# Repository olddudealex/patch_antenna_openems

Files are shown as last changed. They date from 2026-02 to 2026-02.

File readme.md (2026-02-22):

# openEMS Microstrip Patch Antenna Array Simulation Framework

## Overview

This is an openEMS-based simulation and analysis framework for designing microstrip patch antenna arrays. It automates electromagnetic FDTD (Finite-Difference Time-Domain) simulations for linear arrays of rectangular patch antennas on dielectric substrates, with a focus on ~5.8 GHz applications for millimeter-wave radar systems.

### Key Capabilities
- Build patch antenna arrays procedurally or from STL 3D models
- Run FDTD electromagnetic simulations
- Extract S-parameters (reflection/transmission coefficients)
- Generate comprehensive analysis plots (impedance, radiation patterns, fields)
- Support parametric sweeps for antenna optimization
- Convert time-domain field data to frequency-domain representations
- Export results as multi-page PDF reports

---

## Project Structure

### Primary Analysis Scripts (Entry Points)

**[patch_line_analysis.py](patch_line_analysis.py)** - Procedural patch line array simulation
- Builds geometry directly in CSXCAD without STL
- Simulates a linear array of microstrip patches
- Default configuration: 5 elements, 14.1×19mm patches, 5.8 GHz
- Generates multi-page PDF with S11, Smith chart, field slices, surface currents, and directivity patterns

**[patch_line_analysis_with_feed.py](patch_line_analysis_with_feed.py)** - STL-based array with explicit feed port
- Loads CAD models (STL) and converts them to CSXCAD materials
- Automatic mesh line extraction from STL edges for accurate discretization
- Lumped port feed specification
- Geometry-driven mesh snapping for improved accuracy

**[patch_analysis.py](patch_analysis.py)** - Single-patch parameter sweeps
- Optimization via parametric length/width/inset sweeps
- Per-sweep PDF with resonance characteristics and impedance trends
- Supports quarter-wave matching transformers

**[patch_2port_analysis.py](patch_2port_analysis.py)** - Two-port network analysis
- Analyzes coupled patch pairs
- Generates S2P files for two-port network analysis

### Supporting Modules

**[utils.py](utils.py)** (1052 lines) - Core post-processing library
- **HDF5 Data I/O**: Parse openEMS time-domain field dumps
- **Frequency-Domain Conversion**: DFT and FFT-based spectrum extraction
- **Field Visualization**: 2D colormaps, line cuts, surface current density
- **Network Analysis**: Smith charts, S-parameter plots with bandwidth annotations
- **Parameter Conversions**: S↔ABCD↔Z0 transformations
- **File Export**: Touchstone file generation (.s1p, .s2p)
- **Radiation Patterns**: Directivity plots (linear/dB, polar/Cartesian)

**[stl_model.py](stl_model.py)** - CAD material builder
- Creates CSXCAD structure from STL files
- Loads materials from `freecad_macro_output/`:
  - `top_gen_model.stl` → PEC material (patches)
  - `bottom_gen_model.stl` → Ground plane
  - `substrate_gen_model.stl` → Dielectric
- Assigns material priorities for overlap handling

**[extract_edges_from_stl.py](extract_edges_from_stl.py)** - Mesh extraction tool
- Extracts axis-aligned edges from STL models
- Generates CSV files with mesh coordinates (x, y, z)
- Configurable angle and position tolerances
- Usage: `extract_edges_from_stl.main(["path/to/model.stl"])`

**[apply_meshlines_from_csv.py](apply_meshlines_from_csv.py)** - Grid configuration
- Applies extracted meshlines to CSXCAD grid
- Snaps FDTD grid points to STL geometry edges
- Supports coordinate scaling for unit conversion

---

## Technology Stack

| Component | Purpose |
|---|---|
| **openEMS** | FDTD electromagnetic solver (core physics engine) |
| **CSXCAD** | 3D geometry CAD engine |
| **NumPy** | Numerical array operations and Fourier transforms |
| **Matplotlib** | 2D plotting and multi-page PDF export |
| **h5py** | HDF5 file I/O for field data |
| **scikit-rf** | Network parameter analysis and Smith charts |
| **trimesh** | 3D mesh processing for STL import |

---

## Prerequisites

### System Requirements
- **Python 3.8+** (3.10+ recommended)
- **OpenEMS & CSXCAD** installed with Python bindings
- Windows/Linux/macOS with proper PATH/PYTHONPATH setup

### Installation

```bash
# Install Python dependencies
pip install numpy matplotlib h5py scikit-rf trimesh

# Install openEMS and CSXCAD per official documentation
# Ensure Python modules are importable (update PYTHONPATH if needed)
# On Windows, add DLL directories to PATH
```

---

## Usage

### Quick Start

```bash
# Run procedural patch-line analysis
python patch_line_analysis.py

# Run STL-driven patch-line analysis with feed
python patch_line_analysis_with_feed.py

# Run single patch analysis
python patch_analysis.py
```

### Configuration Parameters

All scripts expose configurable parameters at the top:

```python
# Frequency
f0 = 5.8e9  # Hz - Center frequency
fc = 0.5e9  # Hz - Bandwidth (20 dB corner frequency)

# Substrate (ZYF300CA-P)
substrate_epsR = 3.0
substrate_tan = 0.0018
substrate_thickness = 1.524  # mm

# Patch Geometry
patch_length = 14.1  # mm - Resonant length
patch_width = 19     # mm
patch_number = 5     # Array element count
feed_length = 14.1   # mm
feed_width = 3.9     # mm
feed_R = 50          # Ohm - Feed impedance (50-150Ω typical)

# Output Controls
enable_simulation = 1  # 1: Run FDTD, 0: Post-process only
save_to_pdf = 1       # 1: Batch PDF, 0: Interactive display
draw_CAD = 0          # 1: Preview 3D geometry, 0: Skip
draw_S11 = 1          # Enable/disable specific plots
draw_smith_chart = 1
draw_fields = 1
```

---

## Workflow Pipeline

```
1. Load Configuration
   ↓
2. Build Geometry
   - Procedural: Direct CSXCAD objects
   - STL-based: Load STL → Extract meshlines → Apply grid snapping
   ↓
3. Configure FDTD Solver
   - Set boundary conditions (PML_8)
   - Set excitation (Gaussian pulse)
   - Configure mesh resolution
   ↓
4. Run FDTD Simulation (if enable_simulation=1)
   - Execute openEMS solver
   - Output: HDF5 field dumps (Et.h5, Jt.h5)
   ↓
5. Post-Processing (utils.py)
   - Read HDF5 dumps
   - Convert time-domain → frequency-domain
   - Extract S-parameters
   - Generate visualizations
   ↓
6. Export Results
   - Multi-page PDF report
   - S-parameter files (.s1p, .s2p)
   - Logs and metadata
```

---

## Output Files

### Generated Artifacts

**PDF Reports** - Multi-page analysis with:
- S11 reflection coefficient vs frequency
- Smith chart impedance plots
- E-field snapshots (2D slices)
- Surface current density (magnitude + components)
- Directivity patterns (if NF2FF enabled)

**S-Parameter Files** - Touchstone format (.s1p/.s2p):
- Compatible with RF analysis tools
- Frequency range: typically 4.5–7 GHz
- Example naming: `patch_line_14_1mm_19mm_14_1mm_1mm.s1p`

**Mesh Configuration** - CSV files in `meshlines/`:
- `meshlines_x.csv`, `meshlines_y.csv`, `meshlines_z.csv`
- Coordinate values for FDTD grid optimization

**Temporary Files** - Simulation directory:
- Location: `%TEMP%/patch_line_analysis_TIMESTAMP/`
- Contains: CSX XML, HDF5 field dumps, solver logs

---

## STL-Based Workflow Details

The `patch_line_analysis_with_feed.py` script uses STL geometry:

1. **Expected STL Files** in `./freecad_macro_output/`:
   - `top_gen_model.stl` - PEC patches
   - `bottom_gen_model.stl` - Ground plane
   - `substrate_gen_model.stl` - Dielectric layer
   - Generated by FreeCAD macro exports

2. **Mesh Line Extraction**:
   - Script calls `extract_edges_from_stl.main()` for each STL
   - Generates `meshlines_{x,y,z}.csv` in `meshlines/` directory
   - Axis-aligned edges extracted with configurable tolerances

3. **Grid Application**:
   - `apply_meshlines_from_csv()` reads from `meshlines/` directory
   - Supports coordinate scaling (e.g., mm → m with `scale=1e-3`)
   - Mesh snaps to geometry boundaries for accuracy

4. **Material Assignment**:
   - PEC (priority 10): Conductive patches
   - SUBSTRATE (priority 0): Dielectric layer
   - Ground plane: PEC material

---

## Antenna Design Specifications

### Default Configuration
```
Frequency: 5.8 GHz (C-band radar)
Substrate: ZYF300CA-P
  - Permittivity (εr): 3.0
  - Loss tangent (tan δ): 0.0018
  - Thickness: 1.524 mm
Patch: 14.1 × 19 mm rectangular
Array: 5 elements linear
Feed: 3.9–14.1 mm microstrip line
Impedance: 50–150 Ω (configurable)
Matching: Optional quarter-wave transformers
```

### Simulation Parameters
```
FDTD timesteps: 60,000
End criteria: 1e-5 (-50 dB energy decay)
Boundary conditions: PML_8 (6 faces)
Mesh resolution: λ/20 at f0+fc (~3.4 mm)
Excitation: Gaussian pulse (f0 ± fc)
```

---

## Data Flow Architecture

```
Analysis Script
    ↓
[Build Geometry] ──→ Procedural CSXCAD ──┐
    ↓                                     │
[STL Import] ──→ extract_edges_from_stl ──┤
    ↓            ↓                        │
stl_model.py   meshlines/*.csv           │
(reads from    (writes to meshlines/)    │
freecad_macro_ ↓                         │
output/)   apply_meshlines_from_csv ─────┘
    ↓
[FDTD Solver] ──→ openEMS ──→ HDF5 dumps (temp dir)
    ↓
[Post-Process] ──→ utils.py ──→ read_hdf5_dump()
    ↓                         ↓
    │                    td_to_fd_fft()
    ↓                         ↓
[Visualize] ────────────→ plot_s11(), plot_smith_skrf()
    ↓                    plot_ez_2d(), plot_js_2d()
    │                    plot_directivity_*()
    ↓                         ↓
[Export] ────────────────→ reports/*.pdf + touchstone/*.s1p/.s2p
```

---

## Troubleshooting

### Import Errors

**openEMS or CSXCAD not found**
- Ensure openEMS and CSXCAD are installed with Python bindings
- Verify PATH/PYTHONPATH includes required DLLs and modules (Windows)
- Test: `python -c "import openEMS, CSXCAD"`

**scikit-rf or trimesh not found**
- Install via pip: `pip install scikit-rf trimesh`

### Simulation Issues

**Missing Et.h5/Jt.h5 when enable_simulation=0**
- Re-run with `enable_simulation=1` to regenerate results
- Check temp directory (`%TEMP%/patch_line_analysis_*`) for HDF5 files

**No STL meshlines CSV files appear**
- Ensure `extract_edges_from_stl` runs successfully
- Check that `meshlines/` directory is created (auto-created by script)
- Verify STL file paths in `freecad_macro_output/` are valid
- Check that STL files contain proper meshes

**Simulation fails or crashes**
- Check mesh resolution (too fine → memory issues)
- Verify boundary conditions don't intersect geometry
- Review openEMS error logs in temp directory

---

## Design Patterns

### Configuration-Driven
- All tunable parameters at script top (not in functions)
- Boolean flags for workflow control (`draw_*`, `enable_simulation`)
- Easy parametric sweeps via script modification

### Modular Post-Processing
- Pure functions in `utils.py` (td_to_fd_*, plot_*, conversions)
- Decoupled from FDTD solver → can reuse cached results
- Flexible field slicing with geometry masking

### CAD Integration
- FreeCAD → STL export workflow
- Mesh line extraction for grid optimization
- Material priority system for overlap handling

---

## Project Status

This framework is under active development for antenna design research. The repository contains:
- Multiple parameter sweep campaigns (30+ result PDFs)
- Historical analysis archives in subdirectories
- Evolution from procedural to CAD-based workflows

Recent development focus:
- STL import support for complex geometries
- Mesh optimization and feed modeling
- Documentation and reproducibility improvements

---

## Repository Map

```
├── patch_line_analysis.py              # Main: procedural patch line
├── patch_line_analysis_with_feed.py    # Main: STL-driven analysis
├── patch_analysis.py                   # Main: single patch sweeps
├── patch_2port_analysis.py             # Supplementary: 2-port analysis
├── utils.py                            # Post-processing library
├── stl_model.py                        # STL → CSXCAD conversion
├── extract_edges_from_stl.py           # Mesh line extraction CLI
├── apply_meshlines_from_csv.py         # Grid configuration utility
│
├── freecad_macro_output/               # FreeCAD generated STL models
│   ├── top_gen_model.stl               # PEC patches
│   ├── bottom_gen_model.stl            # Ground plane
│   ├── substrate_gen_model.stl         # Dielectric substrate
│   ├── air_gen_model.stl               # Air volume (optional)
│   └── line_array_openEMS.py           # Auto-generated FreeCAD script
│
├── meshlines/                          # FDTD mesh coordinates
│   ├── meshlines_x.csv
│   ├── meshlines_y.csv
│   └── meshlines_z.csv
│
├── touchstone/                         # S-parameter exports
│   ├── *.s1p                           # Single-port measurements
│   └── *.s2p                           # Two-port measurements
│
└── reports/                            # Analysis PDF reports
    ├── best/                           # Best performing designs
    ├── Hor_Polarity_with_Individual_Feed_Lines/
    ├── Ver_Polarity_with_Individual_Feed_Lines/
    └── Ver_Polarity_with_One_Through_Feed_Line/
```

---

## Summary

This framework integrates openEMS FDTD simulation with comprehensive post-processing for microstrip patch antenna array design. It supports both procedural and CAD-based workflows, with automated S-parameter extraction, field visualization, and professional PDF reporting for parametric design studies and rapid prototyping.

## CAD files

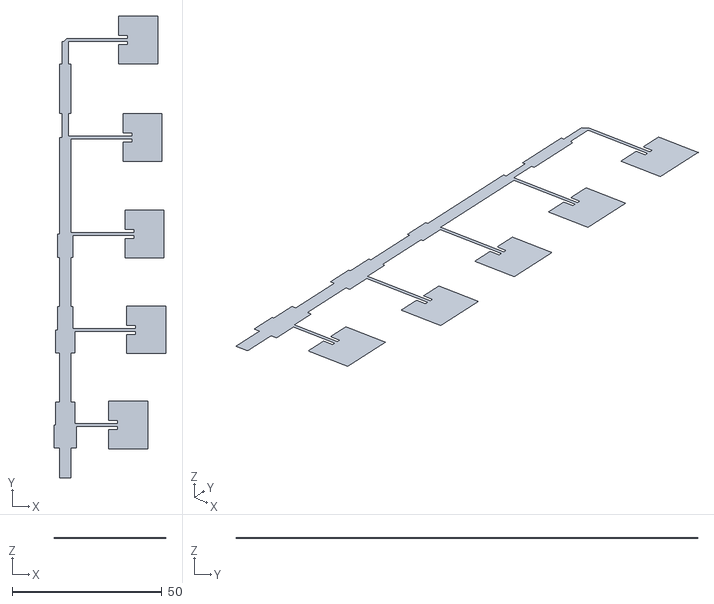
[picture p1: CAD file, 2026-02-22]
freecad_macro_output/top_gen_model.stl
37.3 x 154.3 x 0.035

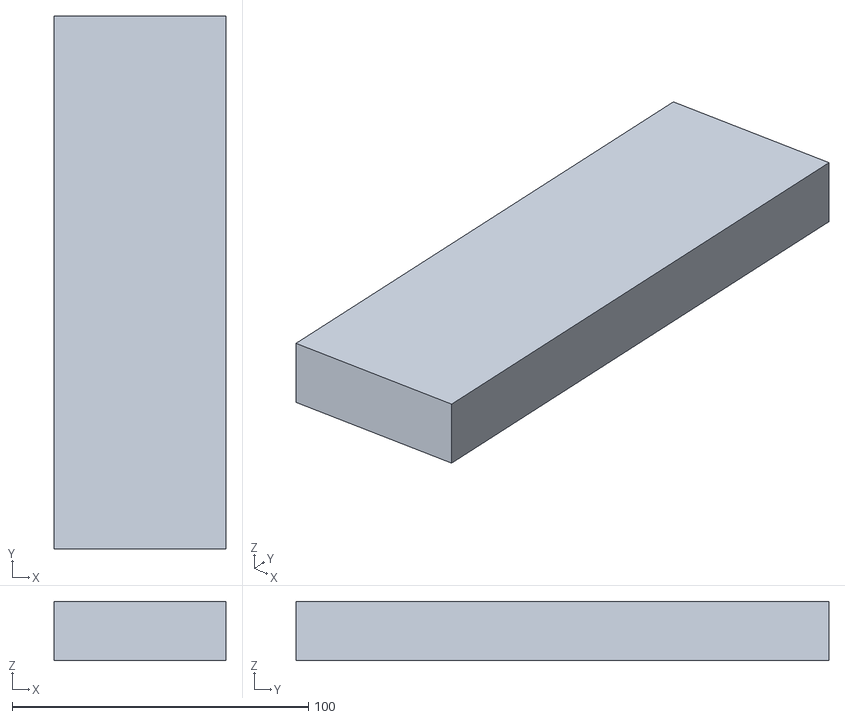
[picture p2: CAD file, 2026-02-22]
freecad_macro_output/air_gen_model.stl
58.0 x 180.0 x 20.0

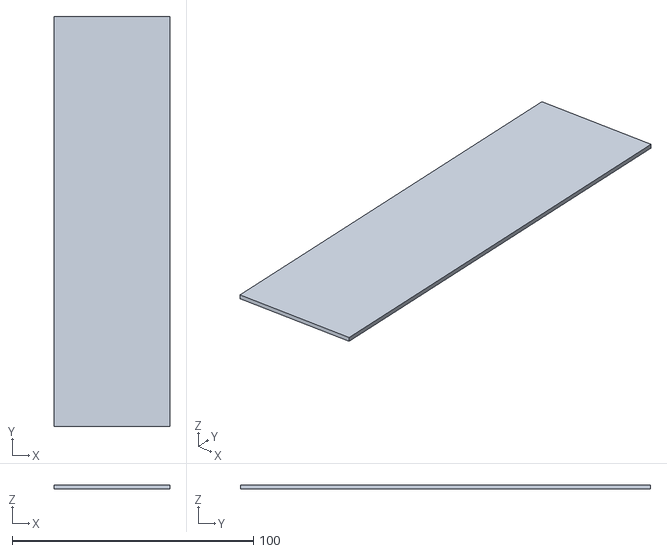
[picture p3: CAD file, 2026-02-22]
freecad_macro_output/substrate_gen_model.stl
48.0 x 170.0 x 1.52

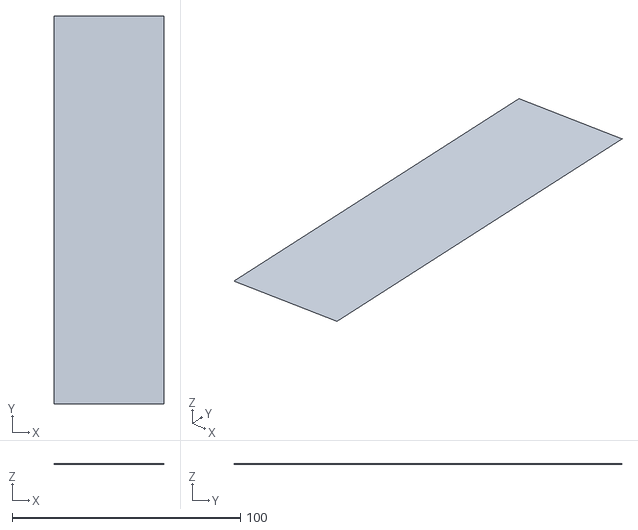
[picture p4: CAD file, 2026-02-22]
freecad_macro_output/bottom_gen_model.stl
48.0 x 170.0 x 0.035

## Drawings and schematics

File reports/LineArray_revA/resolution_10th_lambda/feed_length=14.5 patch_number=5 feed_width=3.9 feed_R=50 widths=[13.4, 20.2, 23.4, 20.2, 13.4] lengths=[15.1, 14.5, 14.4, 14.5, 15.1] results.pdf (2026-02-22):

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

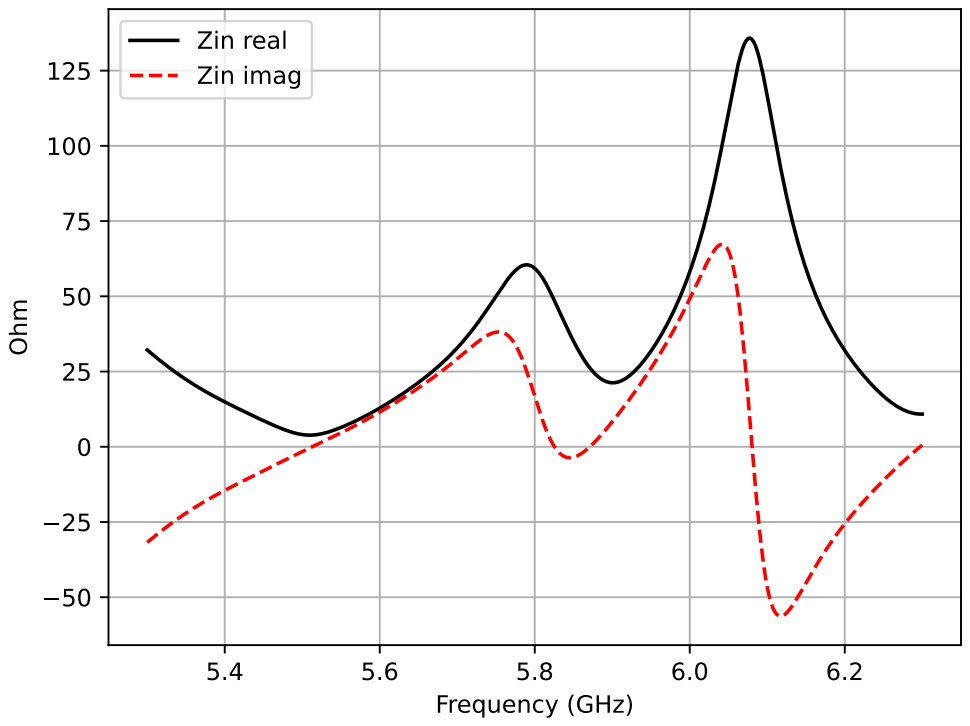
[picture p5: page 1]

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

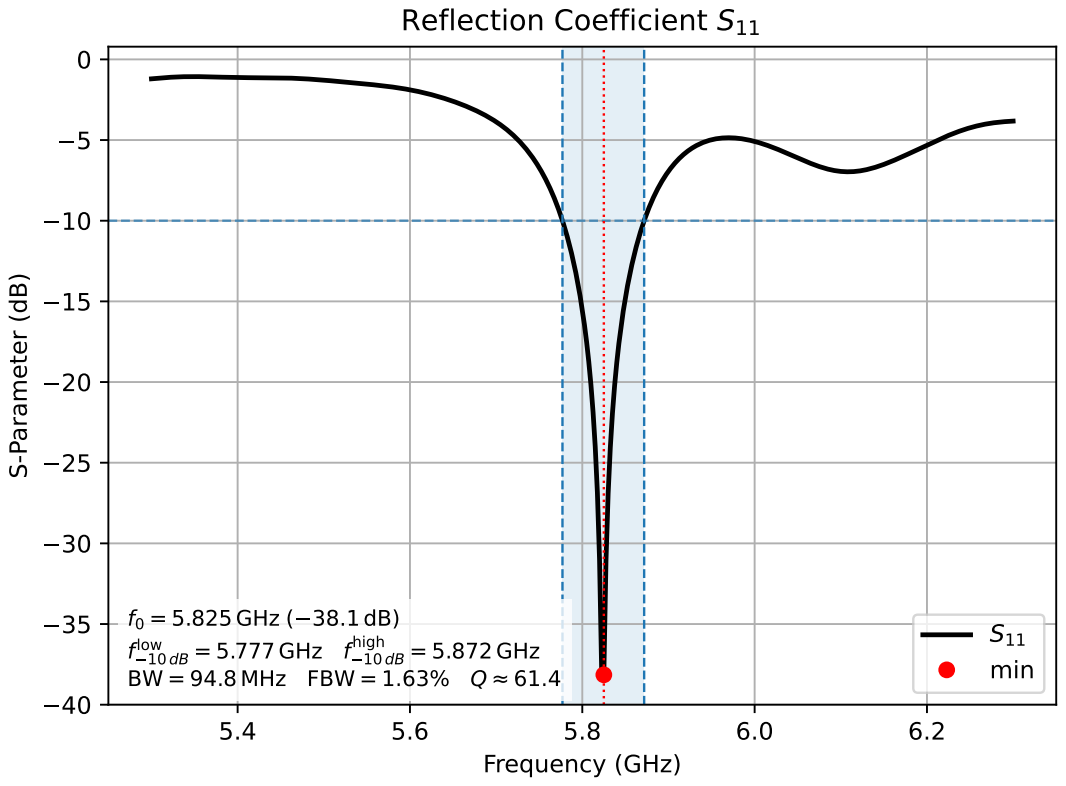
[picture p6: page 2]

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

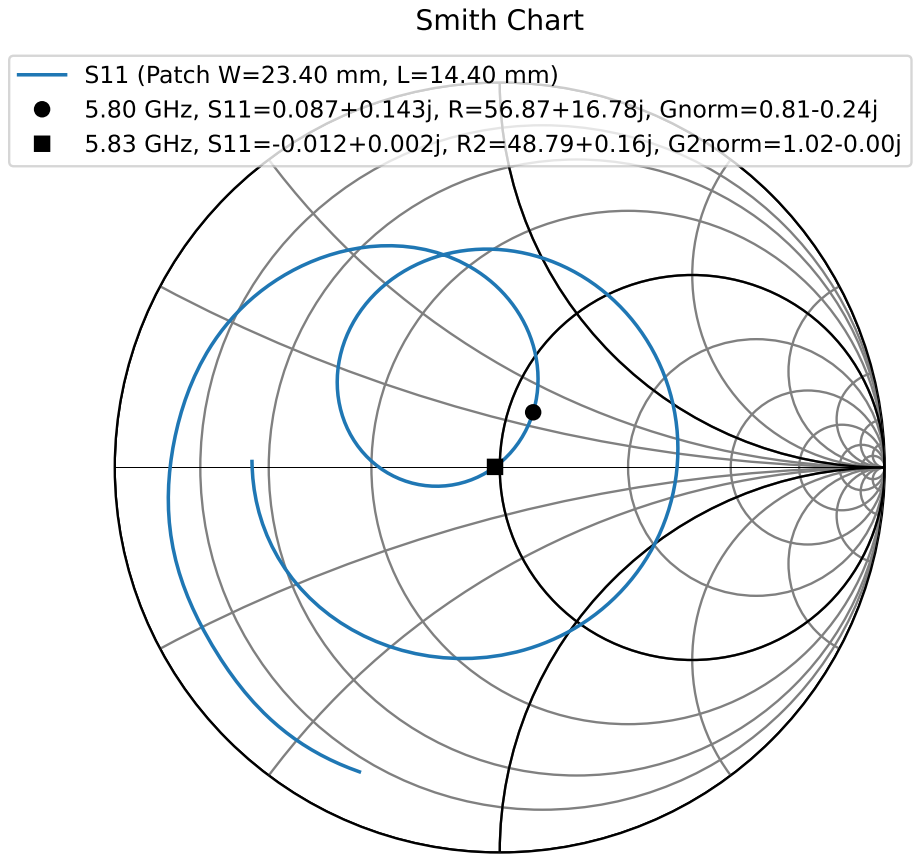
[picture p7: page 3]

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

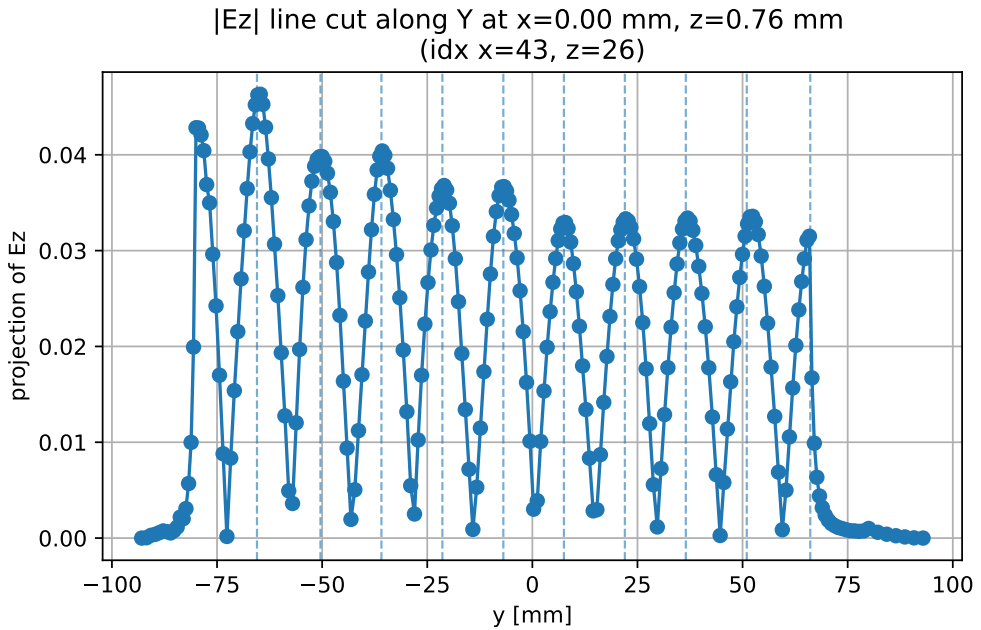
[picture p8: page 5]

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

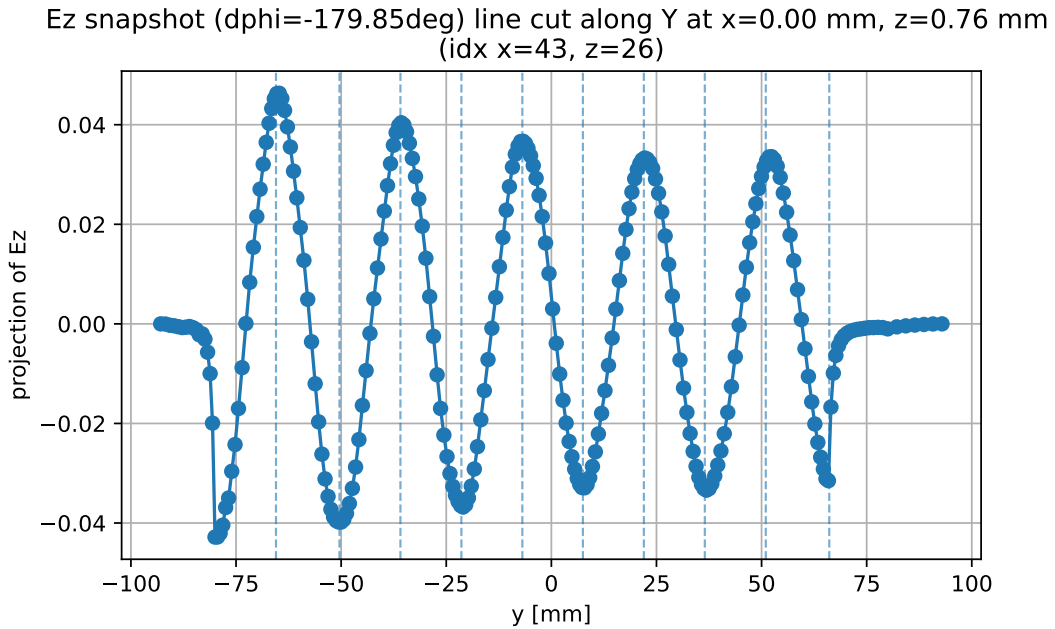
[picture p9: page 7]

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

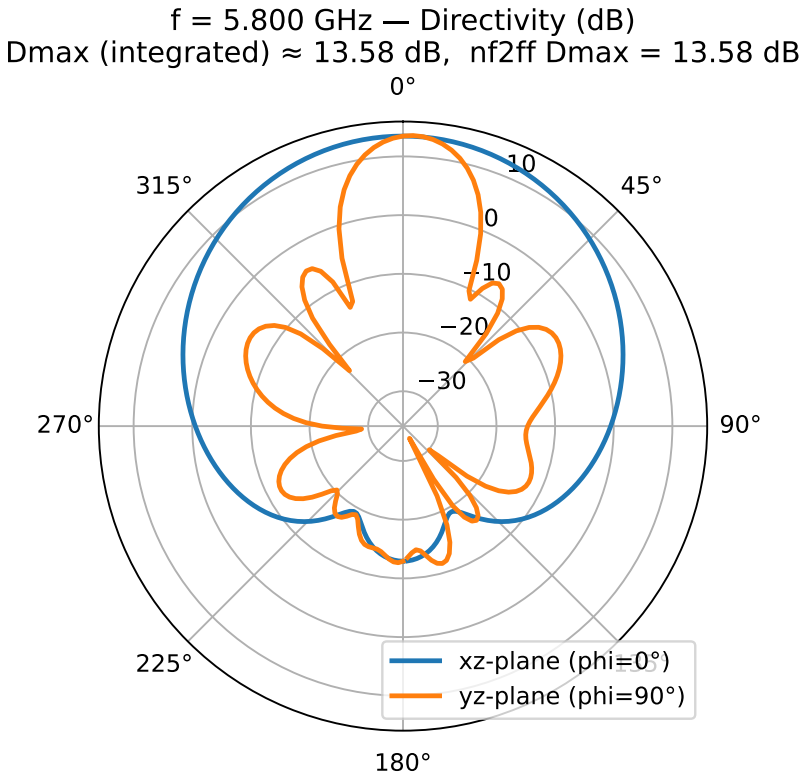
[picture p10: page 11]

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

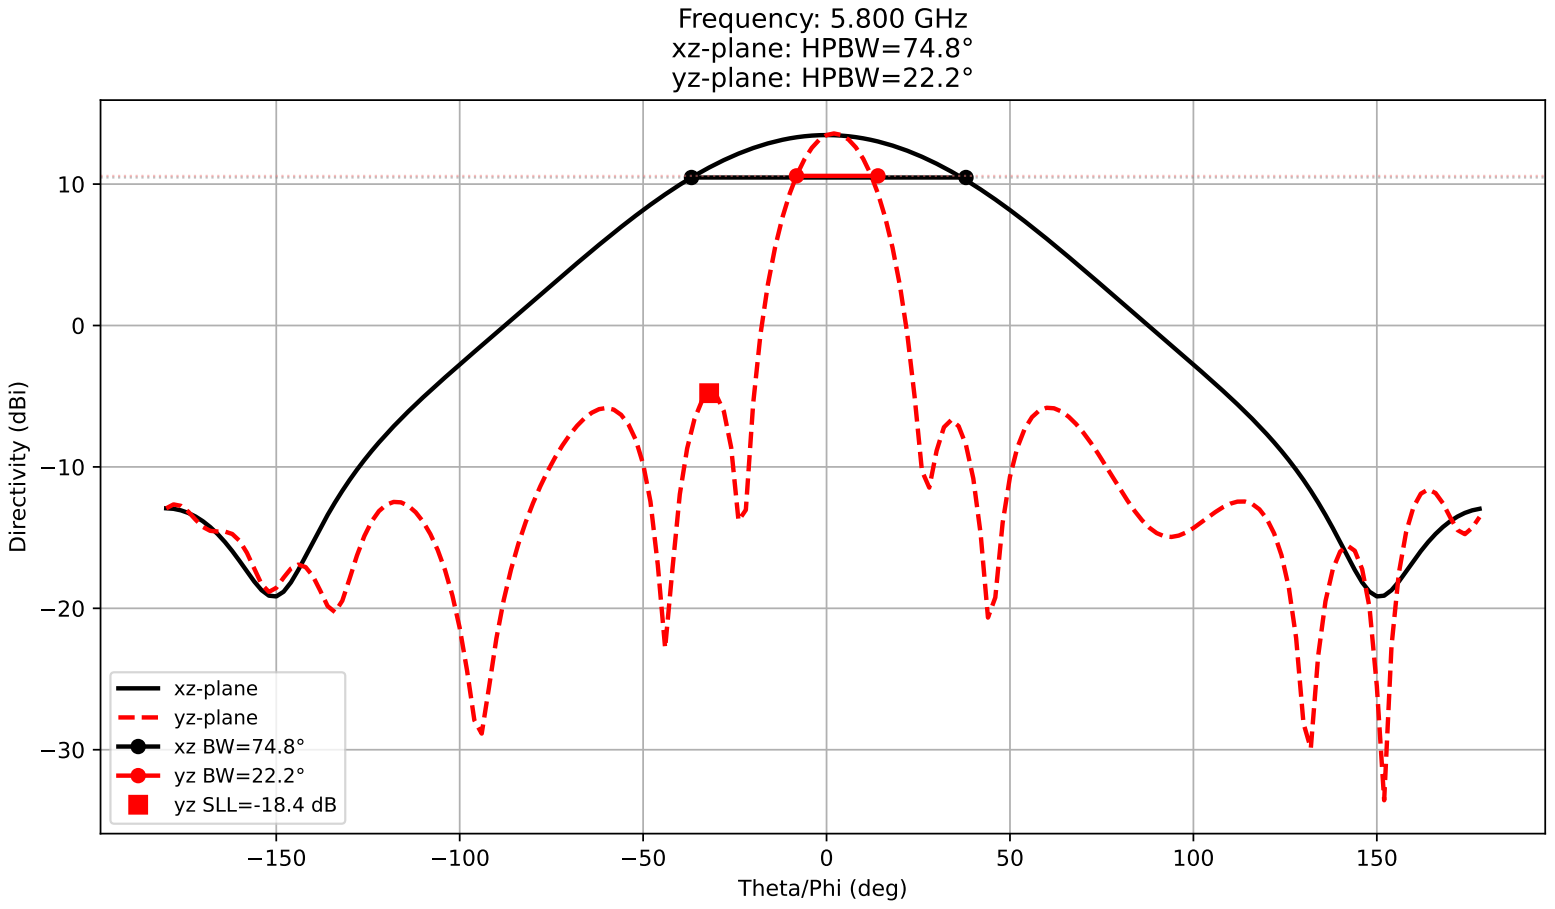
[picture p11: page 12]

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

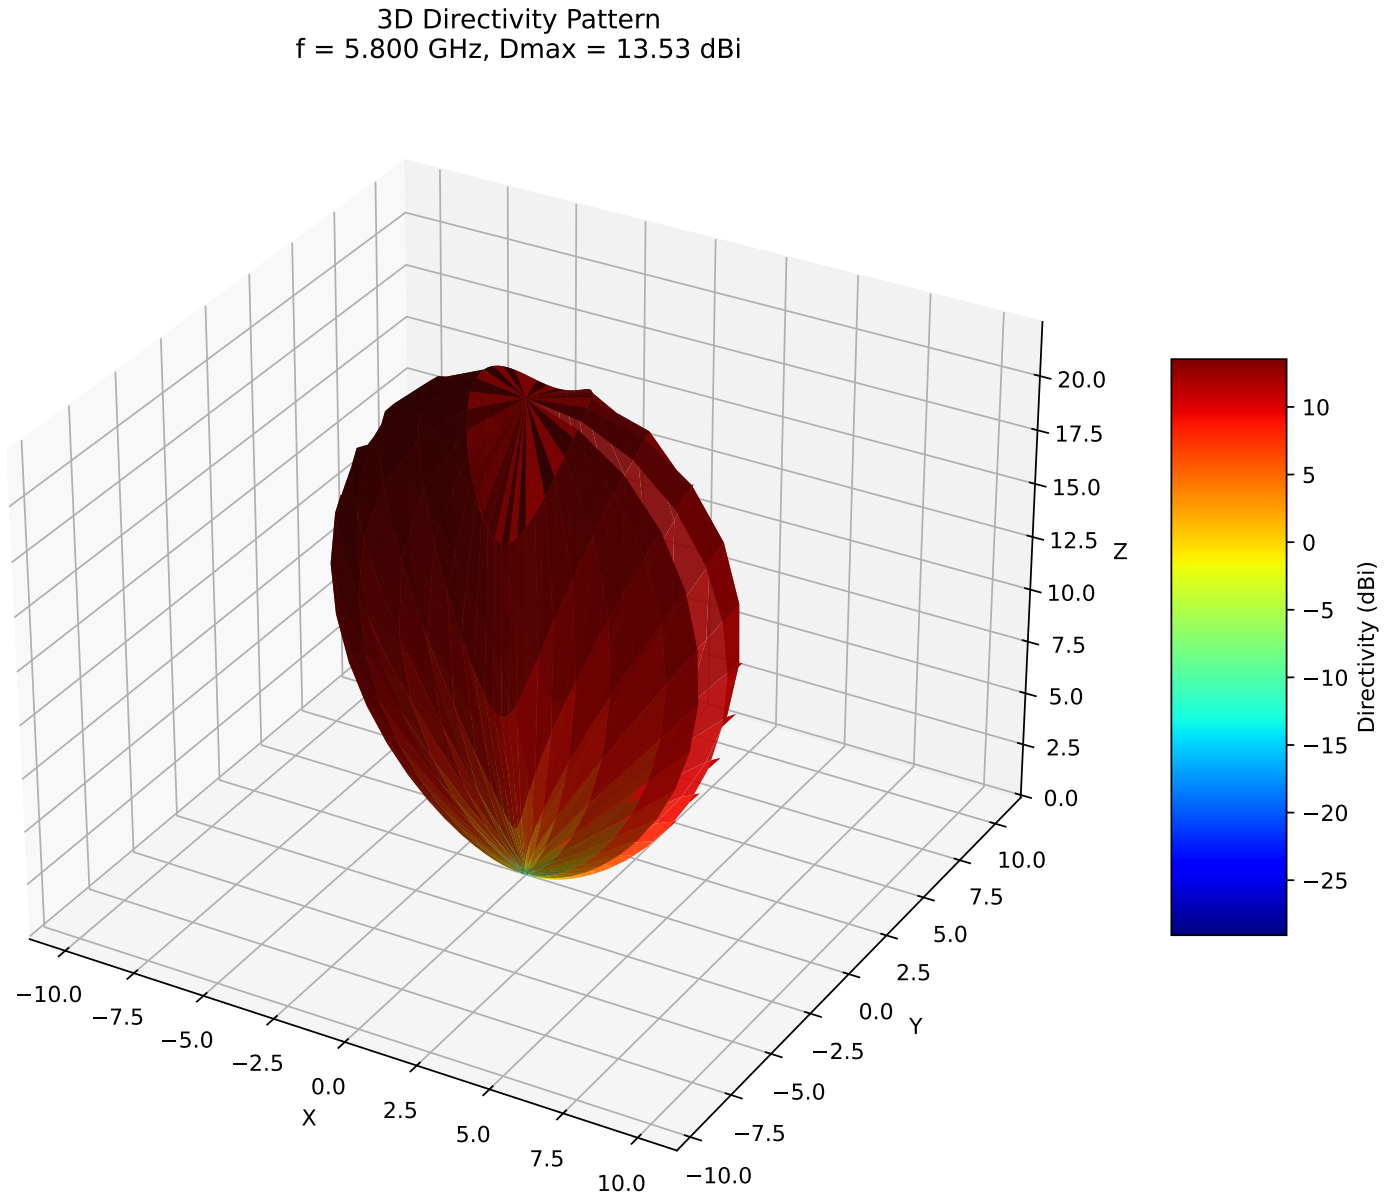
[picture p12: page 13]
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

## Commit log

2025-11-15 Added stl import support
2025-11-30 docs: update readme with comprehensive framework documentation
    - Expand readme with detailed architecture and component descriptions
    - Add workflow pipeline, data flow diagrams, and troubleshooting sections
    - Include technology stack, design patterns, and project status
    - Add .claude to gitignore for local configuration exclusion
2025-11-30 refactor: reorganize project structure with dedicated output directories
    Restructure repository to organize outputs into dedicated directories:
    Directory Structure Changes:
    - freecad_macro_output/ - STL models from FreeCAD macros (was line_array_openEMS_simulation/)
    - meshlines/ - FDTD grid mesh coordinate CSVs
    - touchstone/ - S-parameter exports (.s1p, .s2p files)
    - reports/ - Analysis PDF reports with subdirectories for design variants
    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
    [air_gen_model.stl, bottom_gen_model.stl, meshlines_x.csv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]
2025-11-30 feat: add 3D directivity pattern visualization
    Add comprehensive 3D radiation pattern plotting capability across all
    analysis scripts for better visualization of antenna directivity.
    New Features:
    - plot_directivity_3d() function in utils.py
    - Full 3D surface plot with spherical coordinate conversion
    - Color-coded by directivity (dBi) with colorbar
    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
2025-11-30 feat: add interactive 3D directivity plots with Plotly
    Add interactive HTML-based 3D radiation patterns using Plotly that can be
    rotated, zoomed, and explored in a web browser. These complement the static
    matplotlib 3D plots in PDF reports.
    - plot_directivity_3d_interactive() function in utils.py
    - Generates standalone HTML files using Plotly
    - Interactive surface plot with mouse controls (rotate, zoom, pan)
    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
2025-12-06 feat: auto-include STL geometry in VTK exports for ParaView
    Add automatic STL geometry inclusion in VTK exports to provide complete
    visualization context in ParaView.
    Features:
    - New stl_dir parameter in export_efield_vtk_at_frequency()
    - Automatically copies STL geometry files to VTK output directory
    - Generates comprehensive PVD file with both:
    * E-field animation (time-varying, grouped as "E-field")
    * STL geometry (static, grouped as "Geometry")
    - Geometry appears at all timesteps for consistent context
    Implementation:
    - Copies top_gen_model.stl, substrate_gen_model.stl, bottom_gen_model.stl
    - STL files referenced in PVD with group/part attributes
    - Gracefully handles missing STL fi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
2025-12-06 fix: scale STL geometry to match VTK field data coordinates
    Fix massive scale mismatch between STL geometry (mm) and VTK field
    data (m) that caused ParaView visualization issues.
    Changes:
    - Use trimesh to load, scale, and re-export STL files
    - Scale factor: 1e-3 (millimeters to meters)
    - Applied to all geometry files: top_gen_model.stl, substrate_gen_model.stl, bottom_gen_model.stl
    - Fallback to unscaled copy if trimesh not installed
    This ensures STL geometry and E-field data appear at the same scale
    in ParaView, making visualization coherent.
    Dependency:
    - trimesh library (already in project dependencies)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
2025-12-07 fix: remove STL references from PVD file, keep scaled STL copies
    Remove STL file references from PVD collection due to ParaView
    compatibility issues. STL files are still copied and scaled to the
    VTK directory for manual loading.
    - Removed STL entries from PVD file (ParaView doesn't handle mixed formats well)
    - Kept STL scaling and copying functionality
    - Simplified PVD to contain only VTR E-field animation files
    - Updated console output with instructions for loading STL separately
    Usage in ParaView:
    1. File → Open → E_field_5.8GHz_animation.pvd (E-field animation)
    2. File → Open → *.stl (geometry, select all 3 files)
    3. Both datasets visible, E-field animates while geometr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
2025-12-26 feat: add beamwidth and side lobe analysis to directivity plot
    Add comprehensive radiation pattern analysis to plot_directivity_db function:
    - New helper function calculate_beamwidth_3dB(): calculates -3dB beamwidth
    (HPBW - Half Power Beamwidth) with interpolation for accurate angle
    determination
    - New helper function find_side_lobe_level(): detects and measures maximum
    side lobe level using scipy.signal.find_peaks, excluding main lobe region
    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
2025-12-26 docs: add simulation reports from 2025-12-27
    Add PDF reports from today's patch array antenna parameter sweep:
    - Various width and length weighting configurations
    - Feed length variations (14.3mm, 14.5mm, 15.0mm)
    - Different patch widths (18mm, 18.8mm, 19mm, 19.1mm)
    - Testing uniform vs tapered patch sizing strategies
    All reports now include enhanced beamwidth and side lobe analysis
    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
2026-01-11 refactor: rewrite geometry to align input port with PCB edge
    Replace centered positioning with edge-based sequential construction:
    Old approach:
    - Calculated average patch length and central reference point
    - Used y_shift_first to center the array
    - Positioned components relative to center
    - Used reference_surface_y variable
    New approach:
    - Start from PCB edge: pcb_edge_y = -substrate_length / 2
    - Track position with current_y variable
    - Build forward sequentially:
    1. Matching network at PCB edge
    2. Feed line from matching to first patch
    3. Patches with feed lines between patches
    - Port positioned at PCB edge: feed_pos = pcb_edge_y
    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
2026-02-22 Update simulation parameters, mesh, and gitignore
    - Switch td_to_fd_dft to td_to_fd_fft across all analysis scripts
    - Update patch dimensions to tapered array [13.4..23.4] widths
    - Change mesh resolution from /20 to /10, add edge meshing for feed
    - Merge matching network into feed metal, add 9.7mm input feed line
    - Increase substrate length to 180mm, sim box to match wider array
    - Add conductance vs width plot in patch_analysis.py
    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
    [air_gen_model.stl, bottom_gen_model.stl, meshlines_x.csv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]
